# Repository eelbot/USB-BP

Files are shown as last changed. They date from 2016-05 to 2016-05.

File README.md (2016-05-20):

# USB Booster Pack
## For F28069 and F28377S LaunchPads
The [TMS320F28069U](http://www.ti.com/tool/launchxl-f28069m) and  [TMS320F28377S](http://www.ti.com/tool/LAUNCHXL-F28377S) microcontrollers both have USB D+ and D- pins directly on the chip. This Booster Pack provides a Female USB B connecter as well an input selection jumper, for easier connection to the USB pins.

## Firmware Examples
TI provides many examples for these two microcontrollers in their ControlSuite software. It is freely available online [here](http://www.ti.com/tool/controlsuite).

## Note
The USB connection on the booster pack **does not** supply voltage to the LaunchPad via the 3V3 or 5V pins.

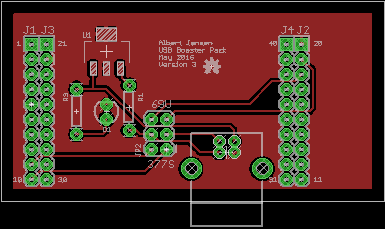
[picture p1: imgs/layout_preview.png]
Board Layout


## To Do
- Final Hardware Tests (need to wait until boards arrive)

## License
<br>
This work is licensed under a [Creative Commons Attribution-ShareAlike 3.0 Unported License](http://creativecommons.org/licenses/by-sa/3.0/)

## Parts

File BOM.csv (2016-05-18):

Part Name | Package | Quantity | Digikey Part Number
2x10 0.1" Female Headers | PTH | 2 | S6106-ND
2x3 0.1" Female Headers | PTH | 1 | 609-3234-ND
2 Pin 0.1" Female Jumper | N/A | 2 | 3M9580-ND
3mm Blue LED (2mA) | PTH | 1 | 754-1914-ND
330 Resistor | 805 | 1 | RMCF0805JT330RCT-ND
1.5k Resistor | 805 | 1 | RMCF0805JT1K50TR-ND
1x2 0.2" Screw Terminal | PTH | 2 | ED2609-ND
1x4 0.2" Screw Terminal | PTH | 4 | ED2611-ND
5V-3.3V LDO | SOT223 | 1 | LM3940IMPX-3.3/NOPBCT-ND
USB Female Socket | PTH | 1 | ED2982-ND

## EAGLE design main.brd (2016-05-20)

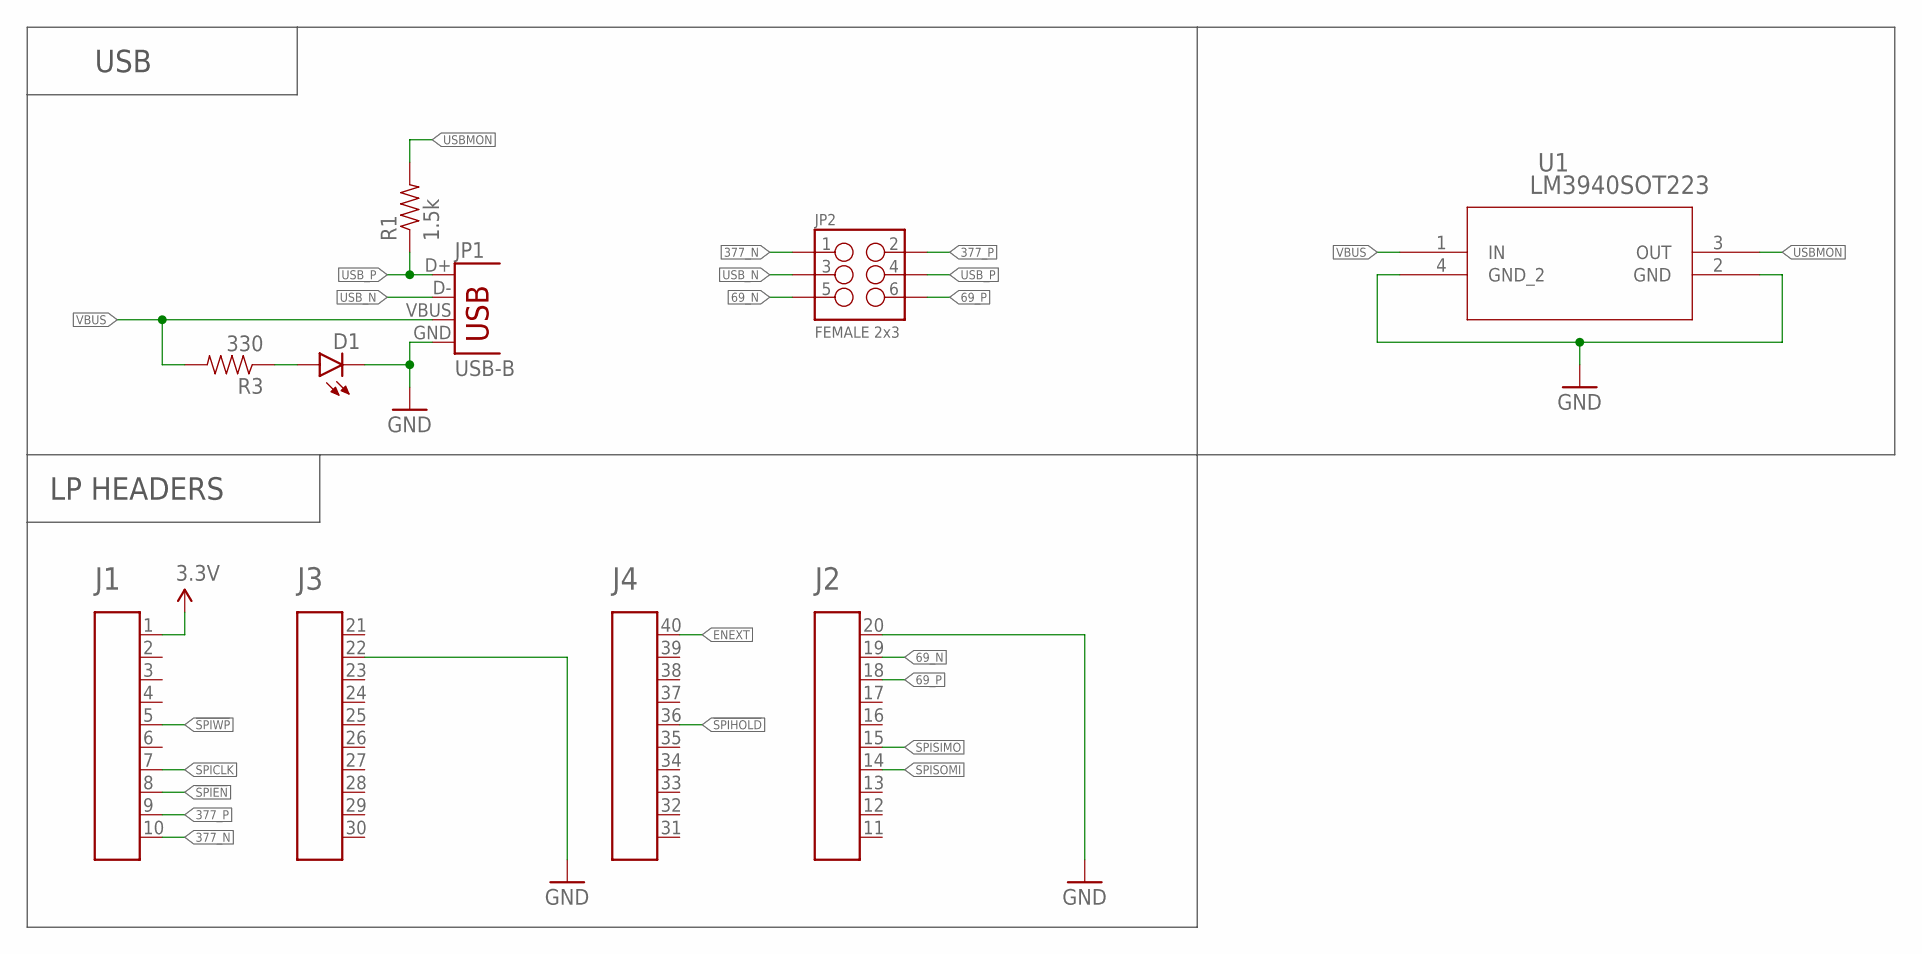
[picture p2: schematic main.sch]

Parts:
A1: HEADER4X10-BOOSTERPACK; 4X10-BOOSTERPACK
D1: LED3MM
JP1: USB-B; USB-B-PTH
JP2: FEMALE 2x3; 2X3
R1: 1.5k; AXIAL-0.3
R3: 330; AXIAL-0.3
U1: LM3940SOT223; DCY

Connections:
3.3V: A1.1
69_N: A1.19, JP2.5
69_P: A1.18, JP2.6
377_N: A1.10, JP2.1
377_P: A1.9, JP2.2
!SPIEN!: A1.8
!SPIHOLD!: A1.36
!SPIWP!: A1.5
ENEXT: A1.40
GND: A1.20, A1.22, D1.K (C), JP1.GND, U1.2 (GND), U1.4 (GND_2)
unnamed: D1.A, R3.P$1 (1)
SPICLK: A1.7
SPISIMO: A1.15
SPISOMI: A1.14
USBMON: R1.P$2 (2), U1.3 (OUT)
USB_N: JP1.D-, JP2.3
USB_P: JP1.D+, JP2.4, R1.P$1 (1)
VBUS: JP1.VBUS, R3.P$2 (2), U1.1 (IN)

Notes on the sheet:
LP HEADERS
USB

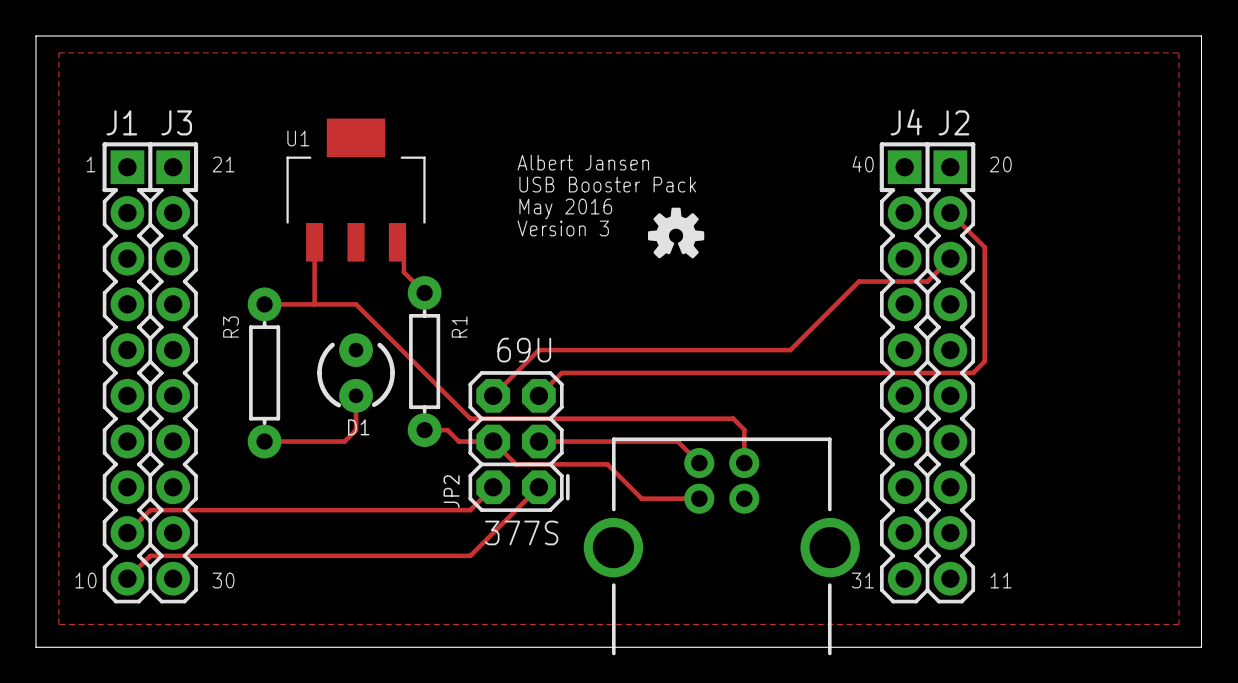
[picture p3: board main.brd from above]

Board: 2 copper layers, 64.8 x 34.0 mm, 8 parts (0 on the bottom side), 10 nets.

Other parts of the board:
U$1: OSHW-LOGO-S

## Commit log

2016-04-03 Designed schematic and routed board
    [main.brd, main.sch]
2016-04-03 Added labels and cleaned up. No electrical changes
    [main.sch]
2016-04-04 Updated small labels. Cleaned up silkscreen layer.
    [main.brd, main.sch]
2016-04-04 Added Name, date, version, and description
    [main.brd]
2016-04-04 Generated Gerbers - Elecrow, 2 layers
2016-04-14 Connected pullup resistor on USB
    [main.brd, main.sch]
2016-04-15 Updated version number
    [main.brd]
2016-05-11 Updated routing and USB power
    [main.brd, main.sch]
2016-05-11 Finalized board against DRC, added aesthetics
    [main.brd]
2016-05-16 Added generic TI USB driver
2016-05-18 Minor update to component values. Added a BOM
    [BOM.csv, main.brd, main.sch]
2016-05-20 Updated to only include hardware files: no need to add examples when TI provides them for free
    [BOM.csv, main.brd, main.sch]
2016-05-20 Finalized documentation and added open source licensing and logos
    [main.brd]

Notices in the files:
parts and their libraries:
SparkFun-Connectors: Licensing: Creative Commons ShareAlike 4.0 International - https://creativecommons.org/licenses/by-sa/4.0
